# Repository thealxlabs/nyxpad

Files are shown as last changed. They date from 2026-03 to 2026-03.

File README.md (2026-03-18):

# ⬡ Nyx Pad

<div align="center">

**Every developer's macropad. Powered by [Conductor](https://github.com/thealxlabs/conductor) AI.**






*by Alexander Wondwossen ([@thealxlabs](https://github.com/thealxlabs)) — Grade 7, Toronto 🇨🇦*

</div>

---

## What is Nyx Pad?

Nyx Pad is a custom 6-key macropad — think DIY Stream Deck — that talks to **Conductor**, my own AI integration CLI. Press a key and Nyx (the [LocalCode](https://github.com/TheLocalCodeTeam/localcode) mascot) animates on the OLED while Conductor fetches weather, crypto prices, GitHub stats, and more.

**3 profiles · hold actions · Pomodoro timer · screensaver · boot greeting**

Built on a Seeed XIAO RP2040 with KMK firmware. Designed from scratch for Hack Club Blueprint. Cost to me: $0.

---

## Features

### Stream Deck style OLED
128×32 OLED shows Nyx as a pixel art character reacting to every keypress. Status bar shows profile and key hints.

### 3 Profiles (encoder hold to switch)
| Profile | Keys |
|---|---|
| **CODE** `</>` | GitHub, system stats, translate, weather, crypto, jokes |
| **CHILL** `uwu` | Music, weather, jokes, quotes, trivia, vibes |
| **MEET** `cam` | Mute, timer, focus, lock, notes, done |

### Key hold (2 seconds)
Every key has a secondary action on hold. K1 hold always starts a **Pomodoro timer**.

### Encoder
- Rotate = volume
- Click = mute
- Hold = switch profile

### Screensaver (30s idle)
Nyx cycles through: batting a hexagon around → getting tired → falling asleep with ZZZs → waking back up.

### Boot greeting
On plug-in, Nyx wakes up with an animation and says *"hey alex!"*

---

## Hardware

| Part | Qty |
|---|-----|
| Seeed XIAO RP2040 | 1 |
| Cherry MX Switches | 6 |
| MX Keycaps 1U | 6 |
| SSD1306 OLED 128×32 (0.91") | 1 |
| EC11 Rotary Encoder | 1 |
| 4.7kΩ Resistor 0402 | 2 |
| 100nF Capacitor 0402 | 1 |
| Custom PCB 80×70mm 2-layer | 1 |
| 3D Printed Case | 1 set |
| M2.5 Screws 6mm | 4 |

---

## Pin Map

| Signal | XIAO Pin |
|---|---|
| K1–K6 | D0–D5 |
| OLED SDA | D6 |
| OLED SCL | D7 |
| Encoder CLK | D8 |
| Encoder DT | D9 |
| Encoder SW | D10 |

---

## Setup

### 1. Flash CircuitPython
Hold BOOT on XIAO while plugging in. Copy [CircuitPython 9.x for XIAO RP2040](https://circuitpython.org/board/seeeduino_xiao_rp2040/) `.uf2` onto the `RPI-RP2` drive.

### 2. Install libraries
Copy to `lib/` on CIRCUITPY:
- `kmk/` from [KMKfw/kmk_firmware](https://github.com/KMKfw/kmk_firmware)
- `adafruit_displayio_ssd1306.mpy`
- `adafruit_display_text/`

### 3. Flash firmware
Copy `Firmware/main.py` to root of CIRCUITPY drive.

### 4. Install Conductor
```bash
curl -fsSL https://raw.githubusercontent.com/thealxlabs/conductor/main/install.sh | bash
conductor ai setup
```

### 5. Run the bridge
```bash
pip install pyserial plyer
python Firmware/bridge.py
```

---

## How it works

```
Key press → KMK sends F-key via USB HID
          → bridge.py reads serial signal
          → calls conductor CLI command
          → result shown as desktop notification
          → OLED shows Nyx reaction
```

---

## Project Structure

```
nyxpad/
├── PCB/                  KiCAD source files
├── CAD/                  OpenSCAD case
├── Firmware/
│   ├── main.py           KMK firmware (drop onto XIAO)
│   └── bridge.py         PC-side Conductor bridge
├── production/           Gerbers, STLs, compiled firmware
├── BOM.csv               Bill of materials
└── README.md
```

---

## Related

- [Conductor](https://github.com/thealxlabs/conductor) — AI CLI powering the keys
- [LocalCode](https://github.com/TheLocalCodeTeam/localcode) — Nyx's home
- [KMK Firmware](https://github.com/KMKfw/kmk_firmware) — keyboard firmware

---

<div align="center">
Made with ❤️ in Toronto for <a href="https://hackclub.com/blueprint">Hack Club Blueprint</a>
</div>

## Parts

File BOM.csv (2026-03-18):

Reference | Value | Quantity | Footprint | Link
U1 | Seeed XIAO RP2040 | 1 | Seeed:XIAO-RP2040 | https://www.seeedstudio.com/XIAO-RP2040-v1-0-p-5026.html
U2 | SSD1306 OLED 128x32 | 1 | PinHeader_1x04 | https://www.amazon.com/dp/B08ZY4YBHL
K1-K6 | Cherry MX Switch | 6 | MX:MX-1U-PCB | https://www.amazon.com/dp/B07K7T4PTG
ENC1 | EC11 Rotary Encoder | 1 | EC11 | https://www.amazon.com/dp/B07D3D64X7
R1-R2 | 4.7k Resistor 0402 | 2 | R_0402 | https://www.amazon.com/dp/B07YDFBX7H
C1 | 100nF Capacitor 0402 | 1 | C_0402 | https://www.amazon.com/dp/B089W4G6M1
PCB | Custom 80x70mm 2-layer | 1 | N/A | https://jlcpcb.com
Case | 3D Printed PLA/PETG | 1 | N/A | Self-printed
MH1-MH4 | M2.5 Screw 6mm | 4 | N/A | Hardware store

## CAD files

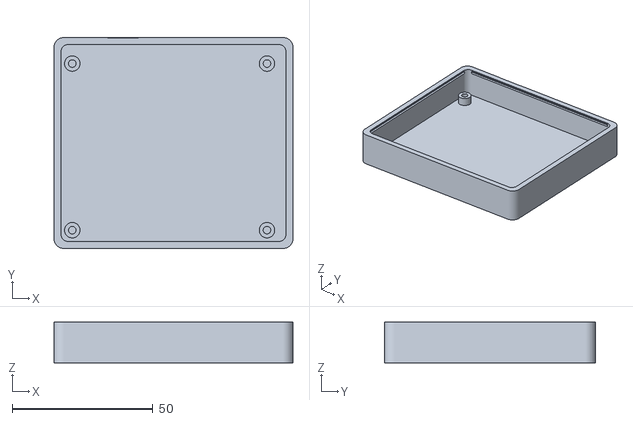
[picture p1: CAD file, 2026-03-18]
CAD/Bottom.stl
85.0 x 75.0 x 14.5

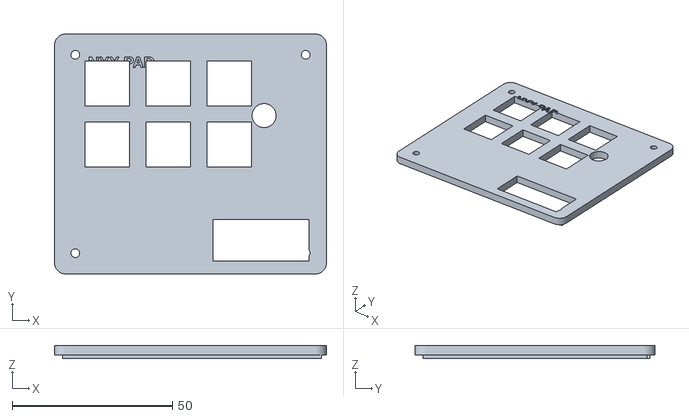
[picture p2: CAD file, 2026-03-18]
CAD/Top.stl
85.0 x 75.0 x 4.20

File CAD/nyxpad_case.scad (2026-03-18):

$fn=64;
WALL=2.5; FLOOR=2.0; TOP_T=3.0; INNER_H=12.5;
PCB_W=80; PCB_D=70; CR=3.5;
KEY_HOLE=14.0; OLED_W=30.0; OLED_H=13.0;
ENC_D=7.5; USB_W=11.0; USB_H=5.0;
SO_H=3.5; SO_OD=5.5; SC=2.7;
SNAP_H=1.2; SNAP_W=1.0;

module rbox(w,d,h,r=CR){
  hull()for(x=[r,w-r],y=[r,d-r])translate([x,y,0])cylinder(r=r,h=h);
}

module standoff(x,y){
  translate([x+WALL,y+WALL,FLOOR])
    difference(){
      cylinder(d=SO_OD,h=SO_H);
      cylinder(d=SC,h=SO_H+0.1);
    }
}

module nyxpad_bottom(){
  difference(){
    rbox(PCB_W+WALL*2,PCB_D+WALL*2,FLOOR+INNER_H);
    translate([WALL,WALL,FLOOR])rbox(PCB_W,PCB_D,INNER_H+0.1,CR-1);
    translate([WALL+22-USB_W/2,PCB_D+WALL*2-0.1,FLOOR+INNER_H-USB_H-1])
      cube([USB_W,WALL+0.2,USB_H+1]);
    translate([WALL-SNAP_W,WALL,FLOOR+INNER_H-SNAP_H-0.5])cube([SNAP_W+0.1,PCB_D,SNAP_H]);
    translate([PCB_W+WALL,WALL,FLOOR+INNER_H-SNAP_H-0.5])cube([SNAP_W+0.1,PCB_D,SNAP_H]);
    translate([WALL,WALL-SNAP_W,FLOOR+INNER_H-SNAP_H-0.5])cube([PCB_W,SNAP_W+0.1,SNAP_H]);
    translate([WALL,PCB_D+WALL,FLOOR+INNER_H-SNAP_H-0.5])cube([PCB_W,SNAP_W+0.1,SNAP_H]);
  }
  standoff(4,4);
  standoff(PCB_W-4-SO_OD/2,4);
  standoff(4,PCB_D-4-SO_OD/2);
  standoff(PCB_W-4-SO_OD/2,PCB_D-4-SO_OD/2);
}

module nyxpad_top(){
  difference(){
    union(){
      rbox(PCB_W+WALL*2,PCB_D+WALL*2,TOP_T);
      translate([WALL,WALL,-SNAP_H])cube([SNAP_W,PCB_D,SNAP_H]);
      translate([PCB_W+WALL,WALL,-SNAP_H])cube([SNAP_W,PCB_D,SNAP_H]);
      translate([WALL,WALL,-SNAP_H])cube([PCB_W,SNAP_W,SNAP_H]);
      translate([WALL,PCB_D+WALL,-SNAP_H])cube([PCB_W,SNAP_W,SNAP_H]);
    }
    for(kx=[14,33.05,52.1],ky=[38,57.05])
      translate([WALL+kx-KEY_HOLE/2,WALL+ky-KEY_HOLE/2,-0.1])
        cube([KEY_HOLE,KEY_HOLE,TOP_T+0.2]);
    translate([WALL+62-OLED_W/2,WALL+8-OLED_H/2,-0.1])
      cube([OLED_W,OLED_H,TOP_T+0.2]);
    translate([WALL+63,WALL+47,-0.1])cylinder(d=ENC_D,h=TOP_T+0.2);
    for(x=[WALL+4,WALL+PCB_W-4],y=[WALL+4,WALL+PCB_D-4])
      translate([x,y,-0.1])cylinder(d=SC,h=TOP_T+0.2);
    translate([WALL+8,WALL+PCB_D-8,TOP_T-0.5])
      linear_extrude(0.6)
        text("NYX PAD",size=3.5,font="Liberation Sans:style=Bold",halign="left");
  }
}

// To export Top.stl:    comment out nyxpad_bottom(), keep nyxpad_top()
// To export Bottom.stl: comment out nyxpad_top(),   keep nyxpad_bottom()
//nyxpad_bottom();
//translate([PCB_W+WALL*2+15,0,0]) nyxpad_top();

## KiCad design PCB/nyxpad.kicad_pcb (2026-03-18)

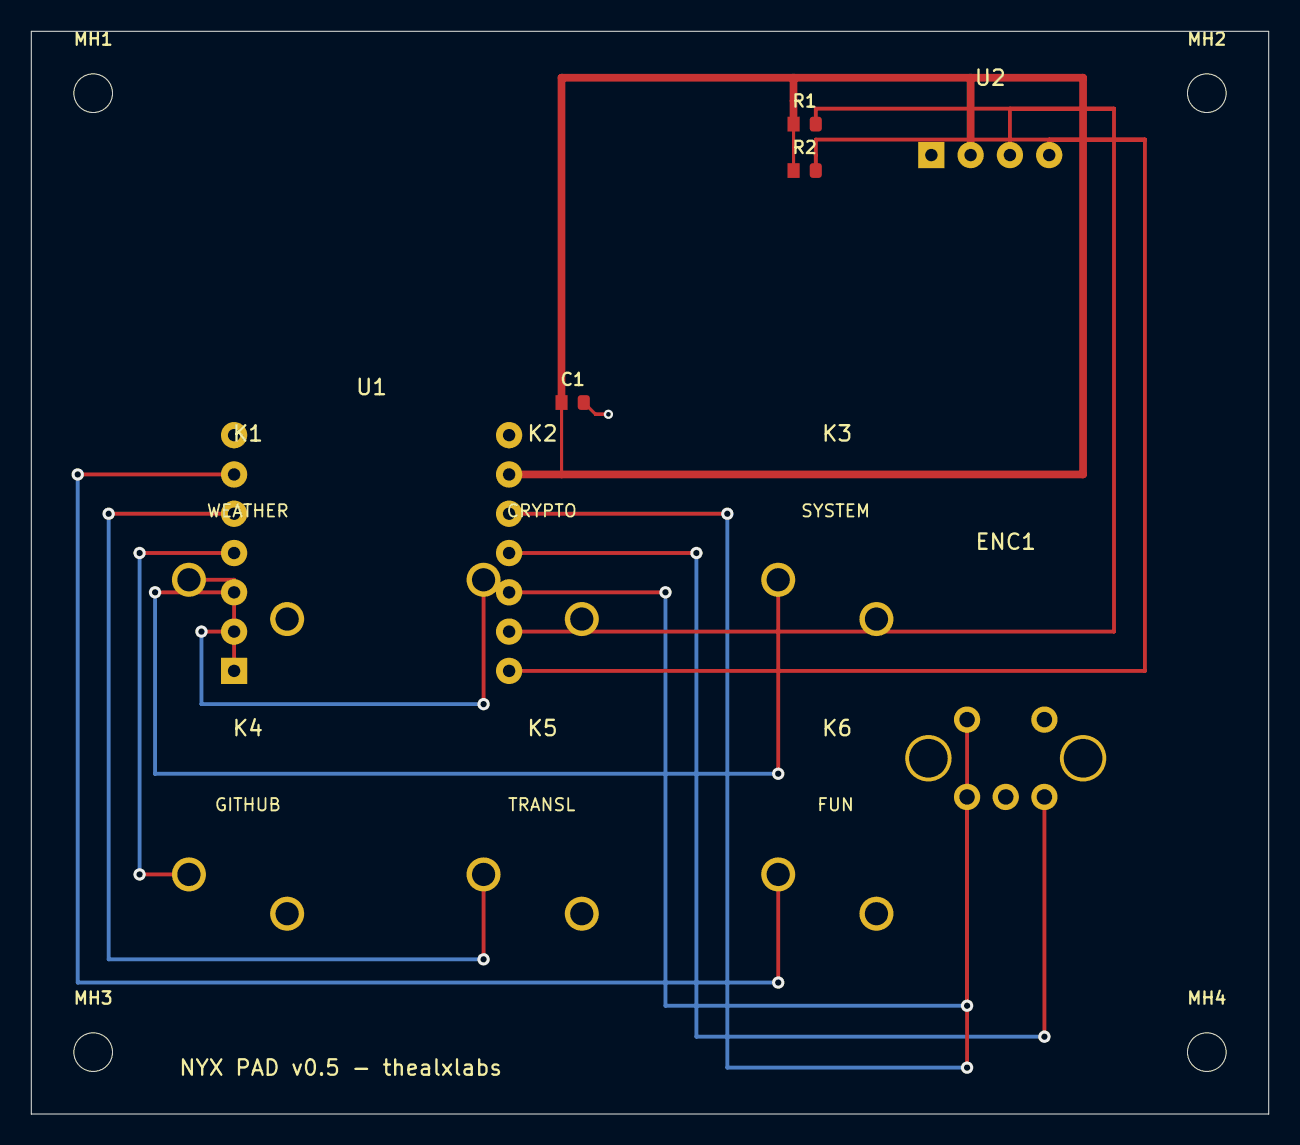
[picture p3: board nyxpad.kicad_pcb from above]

Board: 2 copper layers, 80.0 x 70.0 mm, 16 parts (0 on the bottom side), 13 nets.

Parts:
C1: 100nF; C_0402_1005Metric
ENC1: EC11; RotaryEncoder_Alps_EC11E-Switch_Vertical_H20mm
K1, K2, K3, K4, K5, K6: SW_MX; MX-1U-PCB
MH1, MH2, MH3, MH4: MountingHole_2.5mm
R1, R2: 4.7k; R_0402_1005Metric
U1: XIAO-RP2040; PinHeader_2x07_P2.54mm_Vertical
U2: OLED-SSD1306; PinHeader_1x04_P2.54mm_Vertical

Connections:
3V3: C1.1, R1.1, R2.1, U1.3V3, U2.2
ENC_A: ENC1.A, U1.D8
ENC_B: ENC1.B, U1.D9
ENC_SW: ENC1.SW1, U1.D10
GND: C1.2, ENC1.C, ENC1.SW2, K1.2, K2.2, K3.2, K4.2, K5.2, K6.2, U1.GND_L, U1.GND_R, U2.1
K1_NET: K1.1, U1.D0
K2_NET: K2.1, U1.D1
K3_NET: K3.1, U1.D2
K4_NET: K4.1, U1.D3
K5_NET: K5.1, U1.D4
K6_NET: K6.1, U1.D5
SCL: R1.2, U1.D7, U2.3
SDA: R2.2, U1.D6, U2.4

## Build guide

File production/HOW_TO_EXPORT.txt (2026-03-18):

Add gerbers.zip + Top.stl + Bottom.stl here after exporting

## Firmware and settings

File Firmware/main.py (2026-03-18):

"""
███╗   ██╗██╗   ██╗██╗  ██╗    ██████╗  █████╗ ██████╗
████╗  ██║╚██╗ ██╔╝╚██╗██╔╝    ██╔══██╗██╔══██╗██╔══██╗
██╔██╗ ██║ ╚████╔╝  ╚███╔╝     ██████╔╝███████║██║  ██║
██║╚██╗██║  ╚██╔╝   ██╔██╗     ██╔═══╝ ██╔══██║██║  ██║
██║ ╚████║   ██║   ██╔╝ ██╗    ██║     ██║  ██║██████╔╝
╚═╝  ╚═══╝   ╚═╝   ╚═╝  ╚═╝    ╚═╝     ╚═╝  ╚═╝╚═════╝

Every developer's macropad. Powered by Conductor AI.
by Alexander Wondwossen (@thealxlabs) — Hack Club Blueprint

Hardware : Seeed XIAO RP2040
Keys     : 6x MX switches (D0-D5)
Display  : SSD1306 128x32 OLED (D6=SDA, D7=SCL)
Encoder  : EC11 (D8=CLK, D9=DT, D10=SW)

Features:
  - Stream Deck style OLED display
  - Nyx pixel art mascot with unique reactions per key
  - 3 profiles: Code / Chill / Meet (encoder hold to switch)
  - Key hold (2s) = secondary action
  - Pomodoro timer (hold K1 in any profile)
  - Screensaver: Nyx plays with hexagon, then falls asleep
  - Boot greeting: Nyx wakes up and says hey!
"""

import board, busio, displayio, terminalio, time
from kmk.kmk_keyboard import KMKKeyboard
from kmk.keys import KC
from kmk.scanners.keypad import KeysScanner
from kmk.modules.encoder import EncoderHandler
from kmk.modules.holdtap import HoldTap
from adafruit_display_text import label
import adafruit_displayio_ssd1306

# ── Display ────────────────────────────────────────────────────────────────
displayio.release_displays()
i2c     = busio.I2C(scl=board.D7, sda=board.D6, frequency=400_000)
d_bus   = displayio.I2CDisplay(i2c, device_address=0x3C)
display = adafruit_displayio_ssd1306.SSD1306(d_bus, width=128, height=32)

# ════════════════════════════════════════════════════════════════════════════
# PROFILES
# ════════════════════════════════════════════════════════════════════════════
PROFILES = [
    {
        "name": "CODE", "icon": "[</> ]",
        "idle": [" [^.^] ", " [^-^] ", " [^.^] ", " [>.>] "],
        "keys": [
            {"tap": "GITHUB",  "hold": "TREND",   "ti": "gh", "hi": "tr"},
            {"tap": "SYSTEM",  "hold": "POMODOR", "ti": "sy", "hi": "25"},
            {"tap": "TRANSL",  "hold": "DICT",    "ti": "tr", "hi": "dc"},
            {"tap": "WEATHER", "hold": "FORECAST","ti": "wx", "hi": "7d"},
            {"tap": "CRYPTO",  "hold": "MARKETS", "ti": "$",  "hi": "mk"},
            {"tap": "FUN",     "hold": "QUOTE",   "ti": "ha", "hi": "qt"},
        ]
    },
    {
        "name": "CHILL", "icon": "[uwu]",
        "idle": [" [uwu] ", " [^w^] ", " [uwu] ", " [-w-] "],
        "keys": [
            {"tap": "MUSIC",   "hold": "PLAYLIST","ti": "mu", "hi": "pl"},
            {"tap": "WEATHER", "hold": "FORECAST","ti": "wx", "hi": "7d"},
            {"tap": "JOKE",    "hold": "MEME",    "ti": "ha", "hi": "mm"},
            {"tap": "QUOTE",   "hold": "AFFIRM",  "ti": '"',  "hi": "af"},
            {"tap": "TRIVIA",  "hold": "FACTS",   "ti": "?",  "hi": "fc"},
            {"tap": "VIBE",    "hold": "MOOD",    "ti": "vb", "hi": "md"},
        ]
    },
    {
        "name": "MEET", "icon": "[cam]",
        "idle": [" [o.o] ", " [O.O] ", " [o.o] ", " [-.o] "],
        "keys": [
            {"tap": "MUTE",    "hold": "CAM OFF", "ti": "mu", "hi": "cv"},
            {"tap": "TIMER",   "hold": "POMODOR", "ti": ">>", "hi": "25"},
            {"tap": "FOCUS",   "hold": "DND",     "ti": "[]", "hi": "dn"},
            {"tap": "LOCK",    "hold": "SLEEP",   "ti": "lk", "hi": "sl"},
            {"tap": "NOTES",   "hold": "TODO",    "ti": "nt", "hi": "td"},
            {"tap": "DONE",    "hold": "END ALL", "ti": "ok", "hi": "!!"},
        ]
    },
]

# ════════════════════════════════════════════════════════════════════════════
# NYX ANIMATIONS
# ════════════════════════════════════════════════════════════════════════════
BOOT_SEQ = [
    (" [-.o] ", " booting...   "),
    (" [o.o] ", " nyx pad v1   "),
    (" [^.^] ", " hey alex!    "),
    (" [^.^] ", " lets code :) "),
]

NYX_REACT = [
    (" [*.^] ", " fetching...  "),
    (" [!.!] ", " loading...   "),
    (" [?.?] ", " working...   "),
    (" [~.~] ", " checking...  "),
    (" [$.#] ", " crunching... "),
    (" [^w^] ", " hehe...      "),
]

NYX_DONE = [
    (" [^.^] ", " done!        "),
    (" [^.^] ", " got it!      "),
    (" [^.^] ", " here ya go!  "),
    (" [^.^] ", " fetched!     "),
    (" [uwu] ", " moon!        "),
    (" [uwu] ", " lol!         "),
]

# Screensaver: Nyx bats a hexagon then falls asleep
SS_PLAY = [
    (" [^.^]  ", "  hex >>      "),
    (" [^.^]/ ", "    >> hex    "),
    (" [^o^]/ ", "      hex >>  "),
    (" [^o^]/~", "        >> hex"),
    (" [^-^]  ", "      << hex  "),
    (" [^.^]  ", "    hex <<    "),
    (" [^.^]  ", "  hex <<      "),
    (" [^.^]/ ", "hex >>        "),
]
SS_SLEEP = [
    (" [^.^]  ", " tired...     "),
    (" [-.-]  ", " zzz          "),
    (" [=.=]  ", "  ZZZ         "),
    (" [=.=]  ", "   ZZzz       "),
    (" [=.=]  ", "    Zzzz...   "),
    (" [=.=]  ", "    Zzzz...   "),
    (" [=.=]  ", "    Zzzz...   "),
    (" [^.^]  ", " !  hex >>    "),  # wakes up
]
SS_TYPE = [
    (" [^.^]  ", " tap tap tap  "),
    (" [^-^]  ", " clackclack   "),
    (" [>.<]  ", " CLACK CLACK  "),
    (" [^.^]  ", " tap tap...   "),
]

# ════════════════════════════════════════════════════════════════════════════
# DISPLAY CLASS
# ════════════════════════════════════════════════════════════════════════════
class NyxDisplay:
    SS_TIMEOUT = 30.0

    def __init__(self, disp):
        g = displayio.Group()
        disp.show(g)
        self._face   = label.Label(terminalio.FONT, text=" [-.o] ", color=0xFFFFFF, x=0, y=8)
        self._status = label.Label(terminalio.FONT, text=" booting...   ", color=0x888888, x=0, y=22)
        g.append(self._face)
        g.append(self._status)

        self._profile      = 0
        self._idle_idx     = 0
        self._ss_idx       = 0
        self._ss_phase     = 0   # 0=play, 1=sleep, 2=type
        self._last_idle    = time.monotonic()
        self._last_ss      = time.monotonic()
        self._last_action  = time.monotonic()
        self._state        = "boot"
        self._until        = time.monotonic() + 3.5
        self._boot_idx     = 0
        self._pomo_end     = 0
        self._pomo_on      = False

    @property
    def profile(self): return self._profile

    def wake(self):
        self._last_action = time.monotonic()
        if self._state == "screensaver":
            self._state = "idle"

    def next_profile(self):
        self.wake()
        self._profile = (self._profile + 1) % len(PROFILES)
        p = PROFILES[self._profile]
        self._face.text   = p["icon"]
        self._status.text = f" mode: {p['name']:<8}"
        self._state = "react"
        self._until = time.monotonic() + 1.5

    def react(self, idx, held=False):
        self.wake()
        p = PROFILES[self._profile]["keys"][idx]
        lbl = p["hold"] if held else p["tap"]
        self._face.text   = NYX_REACT[idx][0]
        self._status.text = f" {lbl.lower():<13}"
        self._state = "react"
        self._until = time.monotonic() + 2.5
        print(f"NYX:{'HOLD' if held else 'TAP'}:{idx}:{PROFILES[self._profile]['name']}", flush=True)

    def start_pomodoro(self):
        self.wake()
        self._pomo_on  = True
        self._pomo_end = time.monotonic() + 25 * 60
        self._face.text   = " [>.<] "
        self._status.text = " focus: 25:00  "

    def tick(self):
        now = time.monotonic()

        # Boot
        if self._state == "boot":
            elapsed = now - (self._until - 3.5)
            idx = min(int(elapsed / 0.9), len(BOOT_SEQ) - 1)
            if idx != self._boot_idx:
                self._boot_idx = idx
                f, s = BOOT_SEQ[idx]
                self._face.text, self._status.text = f, s
            if now > self._until:
                self._state = "idle"
                self._last_action = now
            return

        # Pomodoro overlay
        if self._pomo_on:
            rem = self._pomo_end - now
            if rem <= 0:
                self._pomo_on = False
                self._face.text   = " [^o^] "
                self._status.text = " break time!! "
            else:
                self._face.text   = " [>.<] "
                self._status.text = f" focus {int(rem//60):02d}:{int(rem%60):02d}   "
            return

        # React
        if self._state == "react":
            if now >= self._until:
                self._state = "idle"
            return

        # Screensaver
        if now - self._last_action > self.SS_TIMEOUT:
            if self._state != "screensaver":
                self._state   = "screensaver"
                self._ss_idx  = 0
                self._ss_phase = 0
            if now - self._last_ss > 0.5:
                if self._ss_phase == 0:
                    frames = SS_PLAY
                elif self._ss_phase == 1:
                    frames = SS_SLEEP
                else:
                    frames = SS_TYPE
                f, s = frames[self._ss_idx % len(frames)]
                self._face.text, self._status.text = f, s
                self._ss_idx += 1
                if self._ss_idx >= len(frames):
                    self._ss_idx   = 0
                    self._ss_phase = (self._ss_phase + 1) % 3
                self._last_ss = now
            return

        # Idle
        self._state = "idle"
        if now - self._last_idle > 0.7:
            idles = PROFILES[self._profile]["idle"]
            self._idle_idx = (self._idle_idx + 1) % len(idles)
            self._face.text   = idles[self._idle_idx]
            p = PROFILES[self._profile]
            keys = p["keys"]
            hints = " ".join(k["ti"] for k in keys)
            self._status.text = f"[{p['name']}]{hints}"
            self._last_idle = now

nyx = NyxDisplay(display)

# ════════════════════════════════════════════════════════════════════════════
# KEYBOARD
# ════════════════════════════════════════════════════════════════════════════
keyboard = KMKKeyboard()
keyboard.modules.append(HoldTap())
keyboard.matrix = KeysScanner(pins=[
    board.D0, board.D1, board.D2,
    board.D3, board.D4, board.D5,
])

KEYS = [KC.F13, KC.F14, KC.F15, KC.F16, KC.F17, KC.F18]
keyboard.keymap = [KEYS]

enc = EncoderHandler()
keyboard.modules.append(enc)
enc.pins = ((board.D8, board.D9, board.D10, False),)
enc.map  = [((KC.VOLU, KC.VOLD, KC.MUTE),)]

_press_time = {}
HOLD_MS = 2.0

def _on_press(key, keyboard, *args):
    nyx.wake()
    try:
        idx = KEYS.index(key)
        _press_time[idx] = time.monotonic()
        nyx.react(idx, held=False)
    except (ValueError, IndexError):
        pass
    return True

def _on_release(key, keyboard, *args):
    try:
        idx = KEYS.index(key)
        dur = time.monotonic() - _press_time.get(idx, time.monotonic())
        if dur >= HOLD_MS:
            if idx == 0:
                nyx.start_pomodoro()
            else:
                nyx.react(idx, held=True)
        _press_time.pop(idx, None)
    except (ValueError, IndexError):
        pass
    return True

keyboard.before_matrix_scan  = lambda: nyx.tick()
keyboard.on_press_handlers    = [_on_press]
keyboard.on_release_handlers  = [_on_release]

if __name__ == "__main__":
    keyboard.go()

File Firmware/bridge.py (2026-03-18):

#!/usr/bin/env python3
"""
Nyx Pad — PC Bridge v2
Listens for keypresses from the Nyx Pad and calls Conductor CLI plugins.
Supports 3 profiles: CODE / CHILL / MEET

Usage:
    pip install pyserial plyer
    python bridge.py [PORT]

Author: Alexander Wondwossen (@thealxlabs)
"""

import serial, serial.tools.list_ports
import subprocess, threading, time, sys, os

BAUD = 115200
CONDUCTOR = "conductor"

# ── Plugin map per profile ─────────────────────────────────────────────────
ACTIONS = {
    "CODE": {
        "TAP": {
            0: ["conductor", "run", "github",    "user",     "--username", "thealxlabs"],
            1: ["conductor", "run", "system",    "status"],
            2: ["conductor", "run", "translate", "hello",    "--to", "fr"],
            3: ["conductor", "run", "weather",   "current"],
            4: ["conductor", "run", "crypto",    "price",    "--coin", "bitcoin"],
            5: ["conductor", "run", "fun",       "joke"],
        },
        "HOLD": {
            0: ["conductor", "run", "github",    "trending"],
            1: None,  # pomodoro handled on-device
            2: ["conductor", "run", "translate", "--dict"],
            3: ["conductor", "run", "weather",   "forecast", "--days", "7"],
            4: ["conductor", "run", "crypto",    "trending"],
            5: ["conductor", "run", "fun",       "quote"],
        }
    },
    "CHILL": {
        "TAP": {
            0: ["conductor", "run", "fun",       "fact"],
            1: ["conductor", "run", "weather",   "current"],
            2: ["conductor", "run", "fun",       "joke"],
            3: ["conductor", "run", "fun",       "quote"],
            4: ["conductor", "run", "fun",       "trivia"],
            5: ["conductor", "run", "fun",       "random"],
        },
        "HOLD": {
            0: ["conductor", "run", "fun",       "fact"],
            1: ["conductor", "run", "weather",   "forecast", "--days", "7"],
            2: ["conductor", "run", "fun",       "meme"],
            3: ["conductor", "run", "fun",       "affirmation"],
            4: ["conductor", "run", "fun",       "fact"],
            5: ["conductor", "run", "fun",       "mood"],
        }
    },
    "MEET": {
        "TAP": {
            0: [None],   # Mute — handled by system shortcut
            1: [None],   # Timer — on device
            2: [None],   # Focus mode — TBD
            3: [None],   # Lock screen — system
            4: ["conductor", "run", "fun",       "quote"],
            5: [None],   # Done
        },
        "HOLD": {
            0: [None],   # Cam off
            1: [None],   # Pomodoro
            2: [None],   # DND
            3: [None],   # Sleep
            4: ["conductor", "run", "fun",       "todo"],
            5: [None],   # End all
        }
    }
}

def notify(title, msg):
    try:
        from plyer import notification
        notification.notify(title=title, message=msg[:256], app_name="Nyx Pad", timeout=5)
    except Exception:
        print(f"\n┌─ {title} ───────────────────")
        print(f"│  {msg[:200]}")
        print("└────────────────────────────────\n")

def run_action(action_type, key_idx, profile):
    cmd = ACTIONS.get(profile, ACTIONS["CODE"]).get(action_type, {}).get(key_idx)
    if not cmd or cmd[0] is None:
        return
    print(f"[nyx] {profile}/{action_type}/K{key_idx+1}: {' '.join(cmd)}")
    try:
        r = subprocess.run(cmd, capture_output=True, text=True, timeout=15)
        out = (r.stdout or r.stderr or "Done.").strip()
        lines = [l for l in out.splitlines() if l.strip()]
        notify(f"Nyx · {profile} K{key_idx+1}", "\n".join(lines[:3]))
    except subprocess.TimeoutExpired:
        notify("Nyx · Timeout", "Command took too long")
    except FileNotFoundError:
        notify("Nyx · Error", "conductor not found — run install script")
    except Exception as e:
        notify("Nyx · Error", str(e))

def find_port():
    keywords = ["xiao", "rp2040", "circuitpython", "cp2102", "pico"]
    for p in serial.tools.list_ports.comports():
        if any(k in (p.description or "").lower() or k in (p.manufacturer or "").lower() for k in keywords):
            return p.device
    ports = serial.tools.list_ports.comports()
    return ports[0].device if ports else None

def listen(port):
    print(f"[nyx] Connecting on {port}...")
    with serial.Serial(port, BAUD, timeout=1) as ser:
        print("[nyx] Connected! Waiting for keypresses...\n")
        while True:
            line = ser.readline().decode("utf-8", errors="ignore").strip()
            if not line.startswith("NYX:"): continue
            parts = line.split(":")
            if len(parts) < 4: continue
            _, action, idx_str, profile = parts[0], parts[1], parts[2], parts[3]
            try:
                idx = int(idx_str)
                threading.Thread(
                    target=run_action,
                    args=(action, idx, profile),
                    daemon=True
                ).start()
            except (ValueError, IndexError):
                pass

def main():
    print("╔══════════════════════════════════╗")
    print("║   Nyx Pad Bridge  v2             ║")
    print("║   by thealxlabs                  ║")
    print("╚══════════════════════════════════╝\n")
    port = sys.argv[1] if len(sys.argv) > 1 else find_port()
    if not port:
        print("[nyx] No port found. Plug in Nyx Pad or pass port as argument.")
        print("      python bridge.py /dev/ttyACM0   (Linux/Mac)")
        print("      python bridge.py COM3            (Windows)")
        sys.exit(1)
    while True:
        try:
            listen(port)
        except KeyboardInterrupt:
            print("\n[nyx] Bye!")
            break
        except Exception as e:
            print(f"[nyx] Reconnecting in 3s... ({e})")
            time.sleep(3)

if __name__ == "__main__":
    main()

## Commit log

2026-03-18 initial commit - nyxpad v1
    [BOM.csv, nyxpad.kicad_pcb, nyxpad.kicad_sch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]
2026-03-18 initial commit — nyx pad v1
    [Bottom.stl, Top.stl, nyxpad_case.scad]

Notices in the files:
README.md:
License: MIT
